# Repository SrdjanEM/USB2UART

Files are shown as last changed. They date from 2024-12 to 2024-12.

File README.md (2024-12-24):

# USB2UART Programmer

This project provides a simple USB to UART programmer that integrates useful features for programming microcontrollers. It is based on the FTDI FT230 chip and features USB Type-C connectivity, BOOT and EN/RESET buttons, as well as multiple connector options including a UART header and a TC2030 connector.
USB2UART_PROG

---

## Features

1. **USB Type-C Connector**
   - Modern and versatile USB interface for power and data transfer.

2. **FTDI FT230 Chip**
   - Reliable USB to UART communication.
   - Supports various baud rates and low-latency operation.

3. **BOOT and EN/RESET Buttons**
   - Simplifies the programming process by providing dedicated buttons:
     - **BOOT**: Configures the microcontroller for firmware upload.
     - **EN/RESET**: Resets the microcontroller or triggers a reinitialization.

4. **UART Header**
   - Standard 4-pin UART header for easy interfacing with target devices.

5. **TC2030 Connector**
   - Additional programming interface for Tag-Connect cable compatibility.

---

## Applications

- Programming microcontrollers such as ESP32, STM32, and similar.
- Debugging embedded systems.
- Prototyping and testing UART-based devices.

---

## Hardware Components

1. **FTDI FT230 Chip**
   - Manages USB to UART communication.
2. **USB Type-C Connector**
   - Ensures robust and reversible connections.
3. **Push Buttons**
   - **BOOT**: Activates bootloader mode.
   - **EN/RESET**: Triggers a reset of the target device.
4. **Connectors**
   - **UART Header**: Pinout: VCC, TXD, RXD, GND.
   - **TC2030 Connector**: 6-pin layout compatible with Tag-Connect cables.

---

## Pinout

### UART Header:
| Pin | Signal  |
|-----|---|
| 1 | VCC |
| 2 | RXD |
| 3 | TXD |
| 4 | GND |

### TC2030 Connector:
| Pin | Signal  |
|-----|---|
| 1 | VCC |
| 2 | GND |
| 3 | EN |
| 4 | BOOT |
| 5 | TXD |
| 6 | RXD |

---

## Schematic Overview


---

## Usage Instructions

1. **Connect the Programmer**
   - Plug the USB Type-C cable into your computer and the programmer.
   - Connect the UART header or TC2030 connector to your target device.

2. **Install Drivers**
   - Ensure FTDI drivers are installed on your computer. These can be downloaded from the [FTDI website](https://www.ftdichip.com/).

3. **Programming**
   - Press the BOOT button while resetting the device with the EN/RESET button to enter bootloader mode.
   - Use your preferred programming tool (e.g., esptool.py, STM32CubeProgrammer).

4. **Debugging**
   - Monitor UART communication using any serial terminal application.

---

## Additional Notes

- Ensure the target device’s UART voltage levels are compatible with the FT230’s logic level (typically 3.3V).
- The TC2030 connector is designed for Tag-Connect cables, making it ideal for quick and reliable programming connections without the need for soldering headers.
- Use quality USB Type-C cables to ensure stable power and data transmission.
- **USB2UART device also has a 3.3V voltage regulator to allow for powering of devices if they are not 5V compatible.**

---

## License

This project is open-source under the [GNU Public License](LICENSE). Feel free to modify and use it in your projects.

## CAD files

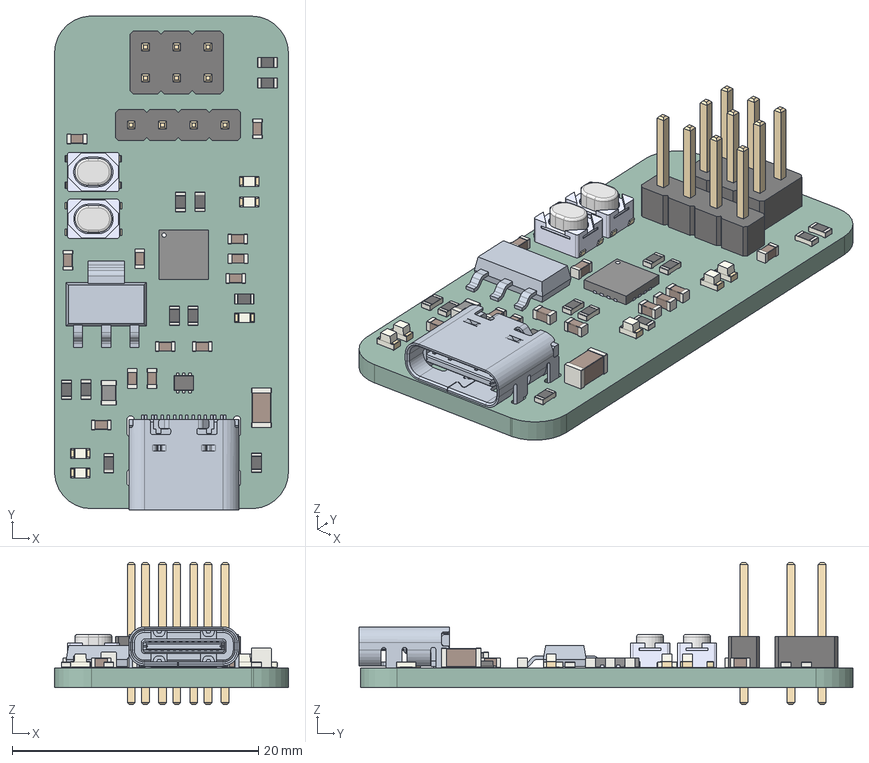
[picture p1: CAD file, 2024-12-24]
USB2UART_PROG/Outputs/3D Model/USB2UART_PROG.step
19.0 x 40.1 x 11.5 mm
C_0603_1608Metric x 12
LED_0603_1608Metric x 5
C_1206_3216Metric
SOT_666
L_0805_2012Metric
R_0603_1608Metric x 11
PinHeader_1x04_P254mm_Vertical
PinHeader_2x03_P254mm_Vertical
USB4105GFA
DCY4
FT230XQ-R
PTS810SJS250SMTR LFS x 2
_autosave-USB2UART_PROG_PCB

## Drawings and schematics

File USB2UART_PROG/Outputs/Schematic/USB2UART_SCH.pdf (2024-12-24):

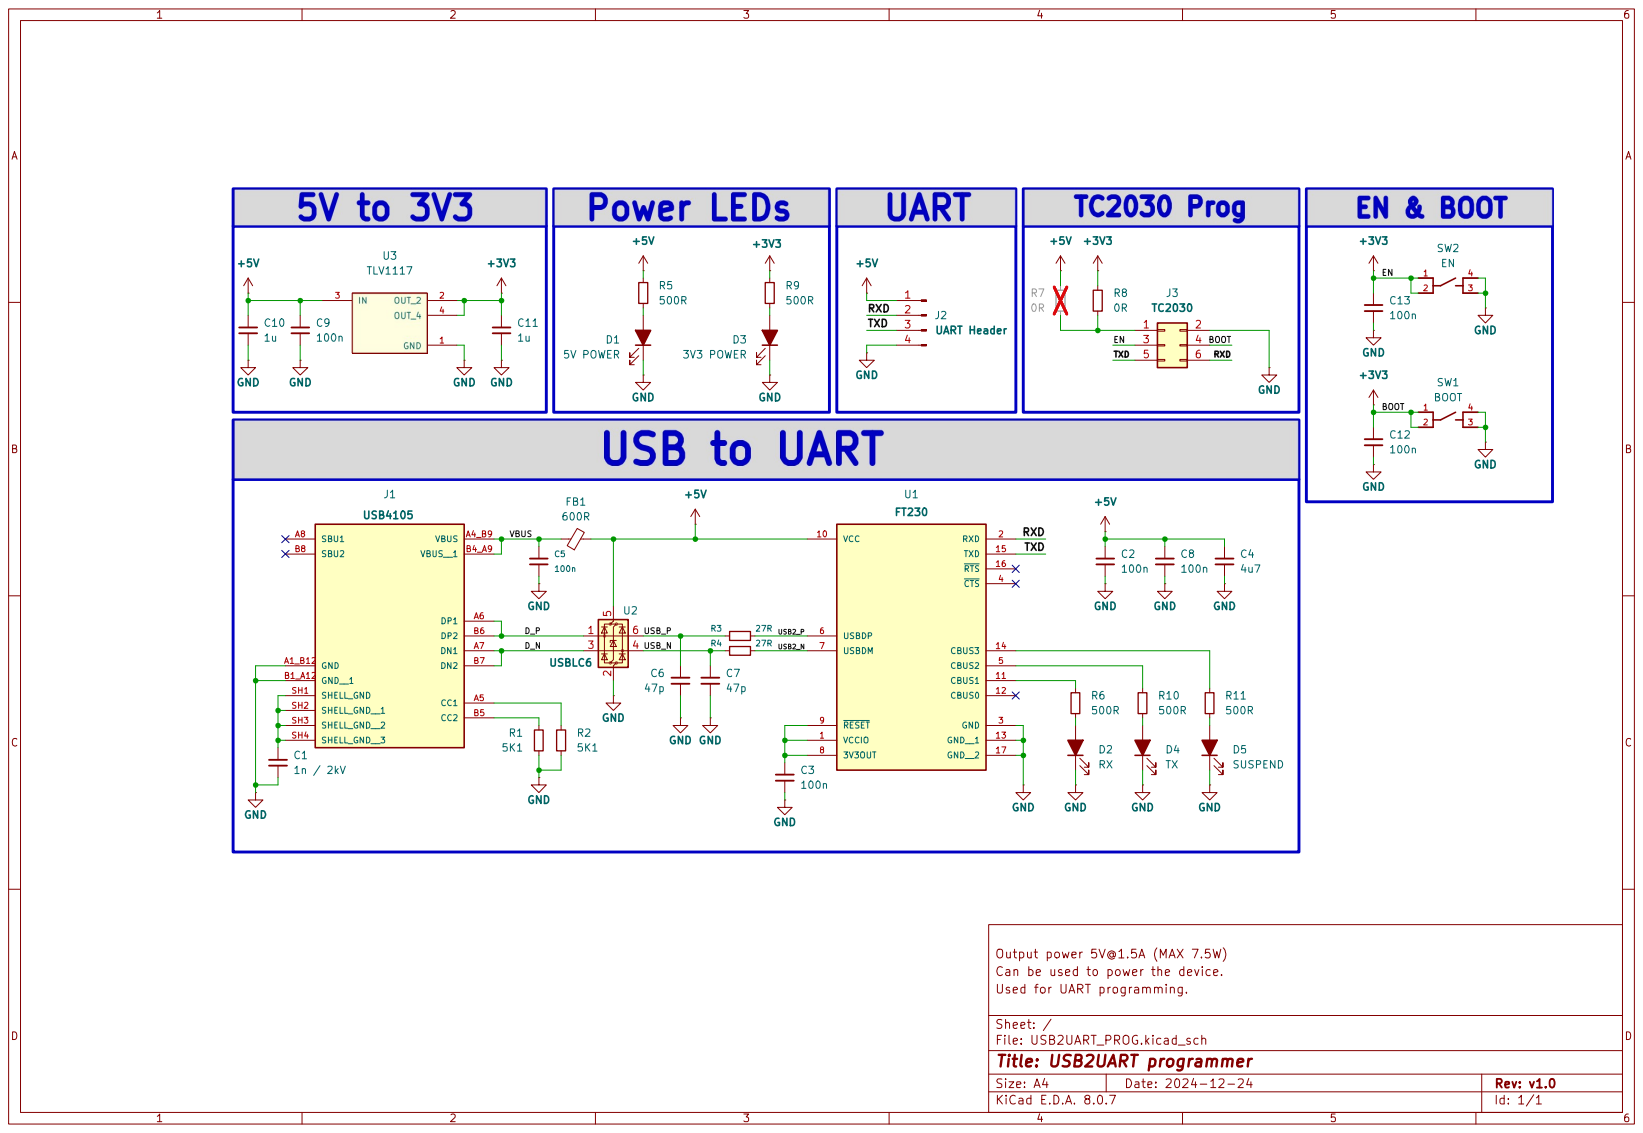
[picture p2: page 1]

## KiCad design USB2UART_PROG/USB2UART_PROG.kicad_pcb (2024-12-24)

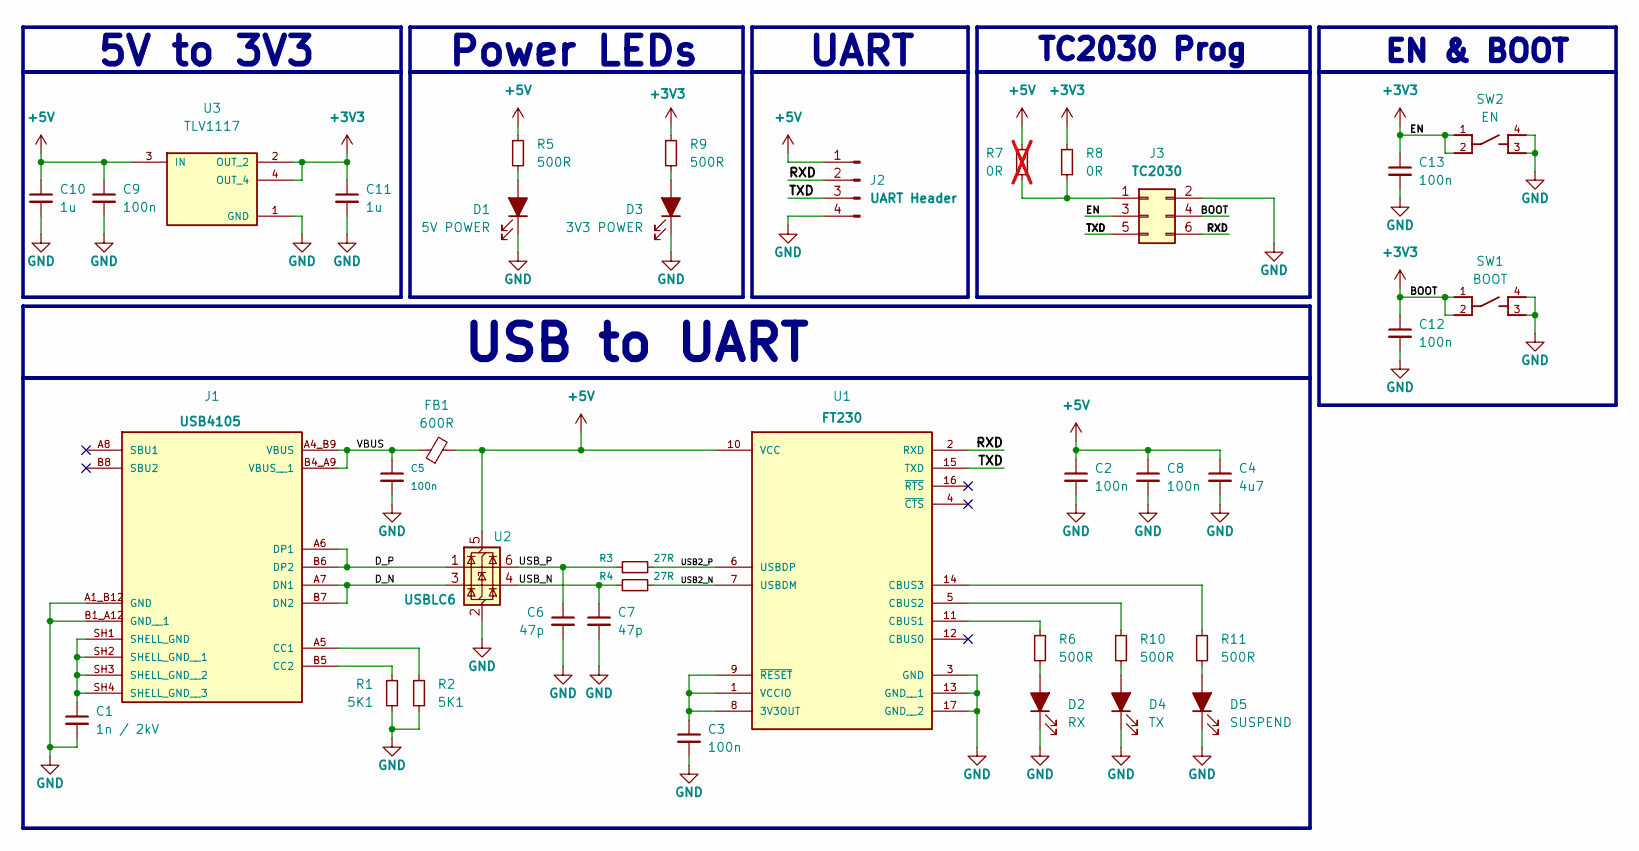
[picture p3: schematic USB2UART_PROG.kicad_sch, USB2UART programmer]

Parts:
C1: 1n / 2kV; C_1206_3216Metric; MPN C1206C102KGRACTU; Digikey stock 614,131 - 24/12/2024
C2, C3, C5, C8, C9, C12, C13: 100n; C_0603_1608Metric; MPN CC0603KRX7R7BB104; Digikey stock 8,314,003 - 23/12/2024
C4: 4u7; C_0603_1608Metric; MPN CL10A475KP8NNNC; Digikey stock 6,283,855 - 23/12/2024
C6: 47p; C_0603_1608Metric; MPN CL10C470JB8NNNC; Digikey stock 8,314,003 - 23/12/2024
C7: 47p; C_0603_1608Metric; MPN CL10C470JB8NNNC; Digikey stock 1,979,713 - 23/12/2024
C10, C11: 1u; C_0603_1608Metric; MPN CC0603KRX7R7BB105; Digikey stock 8,975,196 - 24/12/2024
D1: 5V POWER; LED_0603_1608Metric; MPN 150060GS75000; Digikey stock 129,006 - 23/12/2024
D2: RX; LED_0603_1608Metric; MPN 150060YS75000; Digikey stock 15,103 - 23/12/2024
D3: 3V3 POWER; LED_0603_1608Metric; MPN 150060GS75000; Digikey stock 129,006 - 23/12/2024
D4: TX; LED_0603_1608Metric; MPN 150060YS75000; Digikey stock 15,103 - 23/12/2024
D5: SUSPEND; LED_0603_1608Metric; MPN 150060YS75000; Digikey stock 15,103 - 23/12/2024
FB1: 600R; L_0805_2012Metric; MPN MI0805K601R-10; Digikey stock 319,953 - 23/12/2024
J1: USB4105; MPN USB4105-GF-A; Digikey stock 69,965 - 23/12/2024
J2: UART Header; PinHeader_1x04_P2.54mm_Vertical; MPN 61300411121; Digikey stock 33,682 - 23/12/2024
J3: TC2030; PinHeader_2x03_P2.54mm_Vertical; MPN PH2-06-UA; Digikey stock 7,660 - 24/12/2024
R1, R2: 5K1; R_0603_1608Metric; MPN RC0603FR-075K1L; Digikey stock 1,826,291 - 23/12/2024
R3, R4: 27R; R_0603_1608Metric; MPN RC0603FR-0727RL; Digikey stock 289,460 - 23/12/2024
R5, R6, R9, R10, R11: 500R; R_0603_1608Metric; MPN RT0603BRC07500RL; Digikey stock 24,256 - 23/12/2024
R7: 0R; R_0603_1608Metric; MPN RMCF0603ZT0R00; Digikey stock 4,580,806 - 24/12/2024; not fitted
R8: 0R; R_0603_1608Metric; MPN RMCF0603ZT0R00; Digikey stock 4,580,806 - 24/12/2024
SW1: BOOT; SW_PTS810_SJM_250_SMTR_LFS; MPN PTS815SJM250SMTRLFS; Digikey stock 15,811 - 23/12/2024
SW2: EN; SW_PTS810_SJM_250_SMTR_LFS; MPN PTS815SJM250SMTRLFS; Digikey stock 15,811 - 23/12/2024
U1: FT230; FT230XQ-QFN65P; MPN FT230XQ-R; Digikey stock 39,907 - 23/12/2024
U2: USBLC6; SOT-666; MPN USBLC6-2P6; Digikey stock 48,927 -23/12/2024
U3: TLV1117; VREG_TLV1117LV33DCYR; MPN TLV1117LV33DCYR; Digikey stock 18,033 - 24/12/2024

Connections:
+3V3: C11.1, C12.1, C13.1, J3.3, J3.4, R8.1, R9.1, SW1.1, SW1.2, SW2.1, SW2.2, U3.2 (OUT_2), U3.4 (OUT_4)
+5V: C2.1, C4.1, C8.1, C9.1, C10.1, FB1.2, J2.1, R5.1, R7.1, U1.10 (VCC), U2.5 (VBUS), U3.3 (IN)
/D_N: J1.A7 (DN1), J1.B7 (DN2), U2.3 (I/O2)
/D_P: J1.A6 (DP1), J1.B6 (DP2), U2.1 (I/O1)
/RXD: J2.2, J3.6, U1.2 (RXD)
/TXD: J2.3, J3.5, U1.15 (TXD)
/USB2_N: R4.2, U1.7 (USBDM)
/USB2_P: R3.2, U1.6 (USBDP)
/USB_N: C7.1, R4.1, U2.4 (I/O2)
/USB_P: C6.1, R3.1, U2.6 (I/O1)
/VBUS: C5.1, FB1.1, J1.A4_B9 (VBUS), J1.B4_A9 (VBUS__1)
GND: C1.2, C2.2, C3.2, C4.2, C5.2, C6.2, C7.2, C8.2, C9.2, C10.2, C11.2, C12.2, C13.2, D1.1 (K), D2.1 (K), D3.1 (K), D4.1 (K), D5.1 (K), J1.A1_B12 (GND), J1.B1_A12 (GND__1), J2.4, J3.2, R1.2, R2.2, SW1.3, SW1.4, SW2.3, SW2.4, U1.3 (GND), U1.13 (GND__1), U1.17 (GND__2), U2.2 (GND), U3.1 (GND)
unnamed: D1.2 (A), R5.2
unnamed: D2.2 (A), R6.2
unnamed: D3.2 (A), R9.2
unnamed: D4.2 (A), R10.2
unnamed: D5.2 (A), R11.2
unnamed: J1.A5 (CC1), R2.1
unnamed: J1.B5 (CC2), R1.1
unnamed: C1.1, J1.SH1 (SHELL_GND), J1.SH2 (SHELL_GND__1), J1.SH3 (SHELL_GND__2), J1.SH4 (SHELL_GND__3)
unnamed: J3.1, R7.2, R8.2
unnamed: C3.1, U1.1 (VCCIO), U1.8 (3V3OUT), U1.9 (~RESET)
unnamed: R6.1, U1.11 (CBUS1)
unnamed: R10.1, U1.5 (CBUS2)
unnamed: R11.1, U1.14 (CBUS3)

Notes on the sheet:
5V to 3V3
TC2030 Prog
UART
Power LEDs
USB to UART
EN & BOOT

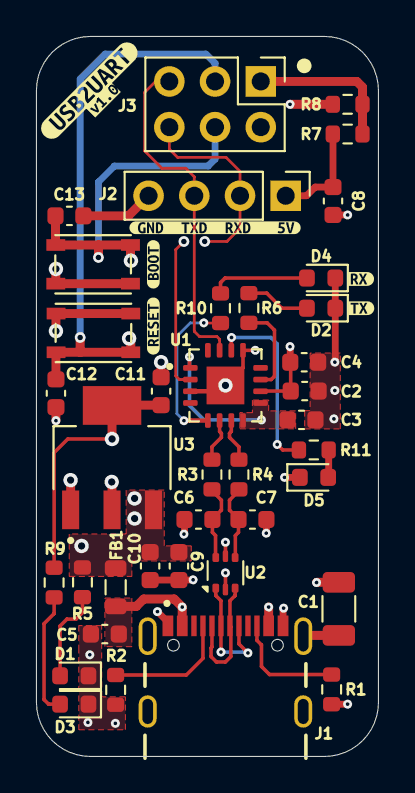
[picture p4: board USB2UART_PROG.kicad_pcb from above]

Board: 4 copper layers, 19.0 x 40.0 mm, 45 parts (0 on the bottom side), 25 nets.

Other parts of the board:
kibuzzard-676AD2A0: G***; kibuzzard-676AD2A0
kibuzzard-676AD2BA: G***; kibuzzard-676AD2BA
kibuzzard-676AD3C3: G***; kibuzzard-676AD3C3
kibuzzard-676AD42F: G***; kibuzzard-676AD42F
kibuzzard-676AD395: G***; kibuzzard-676AD395
kibuzzard-676ADB76: G***; kibuzzard-676ADB76
kibuzzard-676ADB82: G***; kibuzzard-676ADB82

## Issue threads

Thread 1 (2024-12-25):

Missing pullups

SrdjanEM, 2024-12-25:
Missing pullup resistors on EN&BOOT buttons possibly causing a short.

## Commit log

2024-12-24 Added Hardware files
    Add Hardware file that have been created using KiCad 8.0.7
    [USB2UART_PROG-B_Cu.gbr, USB2UART_PROG-B_Mask.gbr, USB2UART_PROG-B_Paste.gbr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]
2024-12-24 BOOT & RESET ISSUE
    Fixed a wrong connection with B&R buttons.
    [USB2UART_PROG.kicad_pcb]
